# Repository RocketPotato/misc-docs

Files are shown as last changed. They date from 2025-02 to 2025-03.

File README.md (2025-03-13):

Unofficial Temporary location for RRLS Rudder Pedals BOM

This is a draft and not the official BOM. Use at your own risk. You will need to compare this with the CAD file avaiable on patreon to make sure you're getting the right parts. (Available here: https://patreon.com/RightRudderLeftStick)
BOM currently missing several parts. Mostly M5 and M8 nuts. Working onupdating and will upload soon. (I will delete this line when I do so)

Currently working on a quick-and-dirty joystick code to get this working with a Teesny 3.2 and adafruit MLX90393 (Teensy is about $35USD and MXL90393 is about $5 each) 
No rhyme or reason for choosing these boards. I had them on-hand. They are certianly more expensive than the bluepill solution used on the RRLS Very-Big-Stick and not compatible with freejoy or MMjoy so I cannot recommend them unless you already have them on hand.
Should work on a teensy 4 as well.
Currently have output from the board with good precision, repeatability, and sensitivity. However it's output as X/Y/Z componenet of the field vector so I'll need to turn that into an angle with some trig and then scale the output. 

This will be removed/hidden when the official BOM is available on patreon or publicly.

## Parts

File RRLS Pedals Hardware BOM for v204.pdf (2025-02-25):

RRLS Rudder Pedals | Version 204 BOM | Total: | | $ | -
(Distributed with cost section left blank due to significant variation in cost and availability of parts based on region)
Common Name | Name in drawing | Units | Unit Cost | Line Item Cost | Notes
Printed Parts | Section Total: $ | -
TBD | Look in drawing tree for details. Check in bodies subfolder to get all parts | Not listed. Guessing about 1.5 to 2kg, but still printing. (will vary significantly based on print settings)
Electronics | Section Total: $ | -
TBD | | | | | | Still in development. No hardware for mounting listed in this version of BOM
Bolts | Section Total: $ | -
M4 20mm SHCS | 91290A168_NO THREADS_Alloy Steel Socket Head Screw | 2 $ | - | $ | -
M5 8mm SHCS | 91290A222_NO THREADS_Alloy Steel Socket Head Screw | 5 $ | - | $ | -
M5 16mm SHCS | 91290A232_NO THREADS_Alloy Steel Socket Heads Screw | 21 $ | - | $ | -
M8 100mm SHCS | 91290A468_Alloy Steel Socket Head Screw | 2 $ | - | $ | - | Drawing shows shoulder bolts but nut placement requires all-thread
M5 20mm SHCS | 91290A242_NO THREADS_Alloy Steel Socket Head Screw | 19 $ | - | $ | -
M5 50mm SHCS | 91290A262_NO THREADS_Alloy Steel Socket Head Screw | 10 $ | - | $ | -
M8 60mm SHCS | 96144A235_Fine-Thread Alloy Steel Socket Head Screw | 4 $ | - | $ | -
M8 35mm SHCS | 96144A223_Fine-Thread Alloy Steel Socket Head Screw | 6 $ | - | $ | -
M6 25mm SHCS | 96144A125_Fine-Thread Alloy Steel Socket Head Screw | 4 $ | - | $ | -
Bearings | Section Total: $ | -
608 Bearing | 5972K501_Ball Bearing | 16 $ | - | $ | - | Does not include 4 608 bearings in toe brake add-on
6003 Bearing | 5972K325_Ball Bearing | 2 $ | - | $ | -
Nuts | Section Total: $ | -
M8 Nylock Nut | 94645A111_High-Strength Steel Nylon-Insert Locknut | 4 $ | - | $ | -
M5 Nylock Nut | 94645A102_NO THREADS_High-Strength Steel Nylon-Insert Locknut | 10 $ | - | $ | -
M8 Lock Washer | 92148A200_18-8 Stainless Steel Split Lock Washer | 2 $ | - | $ | -
M5 T-nut | Not in drawing | 21 $ | - | $ | - | Must be for 2020. Can be hard to find in US but there are a few ebay and amazon sellers
Toe Break Add-on (Optional) | Section Total: $ | - | See comments. BOM differs between fighter and airliner version
608 Bearing | 5972K501_Ball Bearing | 4 $ | - | $ | - | Both versions
M8 35mm SHCS | 96144A223_Fine-Thread Alloy Steel Socket Head Screw | 4 $ | - | $ | - | Both versions
M5 20mm SHCS | 91290A242_NO THREADS_Alloy Steel Socket Head Screw | 16 $ | - | $ | - | Both versions
M3 20mm SHCS | 91290A123_NO THREADS_Alloy Steel Socket Head Screw | 2 $ | - | $ | - | Both versions
M8 Washer | 98269A440_Black-Oxide 18-8 Stainless Steel Washer | 2 $ | - | $ | - | Both versions
M8 35mm SHCS | 96144A223_Fine-Thread Alloy Steel Socket Head Screw | 10 $ | - | $ | - | Combat Pedal Version Only
M5 20mm Flat Head Phillips 92010A328_NO THREADS_Passivated 18-8 stainless Steel Phillips Flat Head Screw 6 $ | - | $ | - | Airline Pedal Version Only
100mm RC Shock | 100mm-RCShock | 2 $ | - | $ | - | Both versions
Piston Damper add-on (optional) | Section Total: $ | -
M5 16mm SHCS | 91290A232_NO THREADS_Alloy Steel Socket Heads Screw | 1 $ | - | $ | -
M5 8mm SHCS | 91290A222_NO THREADS_Alloy Steel Socket Head Screw | 4 $ | - | $ | -
M8 Nylock Nut | 94645A111_High-Strength Steel Nylon-Insert Locknut | 1 $ | - | $ | -
M8 60mm SHCS | 96144A235_Fine-Thread Alloy Steel Socket Head Screw | 1 $ | - | $ | -
M5 T-nut | Not in drawing | 4 $ | - | $ | - | Counted anywhere bolt terminated in extrusion
Piston Damper | OH3A3-19L - ASSY, LEFT PITCH DAMPER | 1 $ | - | $ | - | Exact model unknown. Appears to come in more or less standard sizes
2020 Extrusion lengths | Section Total: $ | - | 1.6 meters needed. Usually sold in increments of 0.5 or 1m in the US
400mm | | 3 $ | - | $ | -
200mm | | 2 $ | - | $ | -
Misc | Section Total: $ | -
FRT-C2-301-G1 Rotary Damper | 2 $ | - | $ | - | optional. Currently only available with very long lead times in US
M4 8mm SHCS | 91290A113_Alloy Steel Socket Head Screw | 4 $ | - | $ | -
Extension Spring | 3630N293_Extenion Spring with Loop Ends | 1 $ | - | $ | - | Used for cam tension. Adjust as desired

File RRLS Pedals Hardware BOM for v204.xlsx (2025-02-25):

RRLS Rudder Pedals | Version 204 BOM |  |  |  | Total: | $37.71
 | pricing sourced from Fastenal in US as many bolts can be purchased individually. Cheaper sources can be found especially if buying in bulk
Common Name | Name in drawing | Units | Sold As | Order Qty | Unit Cost | Line Item Cost | Link | Notes
Printed Parts |  |  |  |  | Section Total: | $0.00
TBD | Look in drawing tree for details. Check in bodies subfolder to get all parts |  |  |  |  |  |  | Not listed. Guessing about 1.5 to 2kg, but still printing. (will vary significantly based on print settings)
Electronics |  |  |  |  | Section Total: | $0.00
TBD |  |  |  |  |  |  |  | Still in development. No hardware for mounting listed in this version of BOM
Bolts |  |  |  |  | Section Total: | $16.22
M4 20mm SHCS | 91290A168_NO THREADS_Alloy Steel Socket Head Screw | 2 | ea | 2 | $0.13 | $0.26 | https://www.fastenal.com/product/details/ZS2530020ZP0000#
M5 8mm SHCS | 91290A222_NO THREADS_Alloy Steel Socket Head Screw | 5 | ea | 5 | $0.09 | $0.43 | https://www.fastenal.com/product/details/11103206#
M5 16mm SHCS | 91290A232_NO THREADS_Alloy Steel Socket Heads Screw | 21 | ea | 21 | $0.10 | $2.17 | https://www.fastenal.com/product/details/ZS2540016ZP0000#
M8 100mm SHCS | 91290A468_Alloy Steel Socket Head Screw | 2 | ea | 2 | $0.55 | $1.10 | https://www.fastenal.com/product/details/0121814# | Drawing shows shoulder bolts but nut placement requires all-thread. Swapped to hex head
M5 20mm SHCS | 91290A242_NO THREADS_Alloy Steel Socket Head Screw | 19 | ea | 19 | $0.11 | $2.16 | https://www.fastenal.com/product/details/11103212#
M5 50mm SHCS | 91290A262_NO THREADS_Alloy Steel Socket Head Screw | 10 | ea | 10 | $0.48 | $4.82 | https://www.fastenal.com/product/details/MS2540050A20000#
M8 60mm SHCS | 96144A235_Fine-Thread Alloy Steel Socket Head Screw | 4 |  | 4 | $0.49 | $1.95 | https://www.fastenal.com/product/details/11113827# | Selected hex head bolt
M8 35mm SHCS | 96144A223_Fine-Thread Alloy Steel Socket Head Screw | 6 |  | 6 | $0.43 | $2.60 | https://www.fastenal.com/product/details/ZS2580035ZP0000#
M6 25mm SHCS | 96144A125_Fine-Thread Alloy Steel Socket Head Screw | 4 |  | 4 | $0.18 | $0.74 | https://www.fastenal.com/product/details/ZS2550025ZP0000#
Bearings |  |  |  |  | Section Total: | $0.00
608 Bearing | 5972K501_Ball Bearing | 16 |  | 16 | $0.00 | $0.00 | Amazon (for return policy) | Does not include 4 608 bearings in toe brake add-on
6003 Bearing | 5972K325_Ball Bearing | 2 |  | 2 | $0.00 | $0.00 | Amazon (for return policy)
Nuts |  |  |  |  | Section Total: | $4.11
M8 Nylock Nut | 94645A111_High-Strength Steel Nylon-Insert Locknut | 4 |  | 4 | $0.59 | $2.36 | https://www.fastenal.com/product/details/1L2580000A40000#
M5 Nylock Nut | 94645A102_NO THREADS_High-Strength Steel Nylon-Insert Locknut | 10 |  | 10 | $0.16 | $1.63 | https://www.fastenal.com/product/details/1L2540000A40000#
M8 Lock Washer | 92148A200_18-8 Stainless Steel Split Lock Washer | 2 |  | 2 | $0.06 | $0.11 | https://www.fastenal.com/product/details/40252#
M5 T-nut | Not in drawing | 21 |  | 21 | $0.00 | $0.00 | Amazon (for return policy) | Must be for 2020. Can be hard to find in US but there are a few ebay and amazon sellers
Toe Break Add-on (Optional) |  |  |  |  | Section Total: | $12.79 |  | See comments. BOM differs between fighter and airliner version
608 Bearing | 5972K501_Ball Bearing | 4 |  | 4 | $0.00 | $0.00 | Amazon (for return policy) | Both versions
M8 35mm SHCS | 96144A223_Fine-Thread Alloy Steel Socket Head Screw | 4 |  | 4 | $0.43 | $1.73 | https://www.fastenal.com/product/details/ZS2580035ZP0000# | Both versions
M5 20mm SHCS | 91290A242_NO THREADS_Alloy Steel Socket Head Screw | 16 |  | 16 | $0.11 | $1.82 | https://www.fastenal.com/product/details/11103212# | Both versions
M3 20mm SHCS | 91290A123_NO THREADS_Alloy Steel Socket Head Screw | 2 |  | 2 | $0.00 | $0.00 |  | Both versions
M8 Washer | 98269A440_Black-Oxide 18-8 Stainless Steel Washer | 2 |  | 2 | $0.11 | $0.21 | https://www.fastenal.com/product/details/MW6380000A40000# | Both versions
M8 35mm SHCS | 96144A223_Fine-Thread Alloy Steel Socket Head Screw | 10 |  | 10 | $0.43 | $4.34 | https://www.fastenal.com/product/details/ZS2580035ZP0000# | Combat Pedal Version Only
M5 20mm Flat Head Phillips | 92010A328_NO THREADS_Passivated 18-8 stainless Steel Phillips Flat Head Screw | 6 |  | 6 | $0.00 | $0.00 |  | Airline Pedal Version Only. No source. Can't find reasonably priced source (didn't try very hard)
100mm RC Shock | 100mm-RCShock | 2 |  | 2 | $0.00 | $0.00 |  | Both versions
Piston Damper add-on (optional) |  |  |  |  | Section Total: | $4.59
M5 16mm SHCS | 91290A232_NO THREADS_Alloy Steel Socket Heads Screw | 1 |  | 1 | $0.10 | $0.10 | https://www.fastenal.com/product/details/ZS2540016ZP0000#
M5 8mm SHCS | 91290A222_NO THREADS_Alloy Steel Socket Head Screw | 4 |  | 4 | $0.85 | $3.40 | https://www.fastenal.com/product/details/11103206#
M8 Nylock Nut | 94645A111_High-Strength Steel Nylon-Insert Locknut | 1 |  | 1 | $0.59 | $0.59 | https://www.fastenal.com/product/details/0121814#
M8 60mm SHCS | 96144A235_Fine-Thread Alloy Steel Socket Head Screw | 1 |  | 1 | $0.49 | $0.49 | https://www.fastenal.com/product/details/11113827#
M5 T-nut | Not in drawing | 4 |  | 4 | $0.00 | $0.00 | Amazon (for return policy) | Counted anywhere bolt terminated in extrusion
Piston Damper | OH3A3-19L - ASSY, LEFT PITCH DAMPER | 1 |  | 1 | $0.00 | $0.00 | Amazon (for return policy) | Exact model unknown. Appears to come in more or less standard sizes
2020 Extrusion lengths |  |  |  |  | Section Total: | $0.00 |  | 1.6 meters needed. Usually sold in increments of 0.5 or 1m in the US
400mm |  | 3 |  | 3 | $0.00 | $0.00
200mm |  | 2 |  | 2 | $0.00 | $0.00
Misc |  |  |  |  | Section Total: | $0.00
FRT-C2-301-G1 Rotary Damper |  | 2 |  | 2 | $0.00 | $0.00 |  | optional. Currently only available with very long lead times in US
M4 8mm SHCS | 91290A113_Alloy Steel Socket Head Screw | 4 |  | 4 | $0.00 | $0.00
Extension Spring | 3630N293_Extenion Spring with Loop Ends | 1 |  | 1 | $0.00 | $0.00 |  | Used for cam tension. Adjust as desired

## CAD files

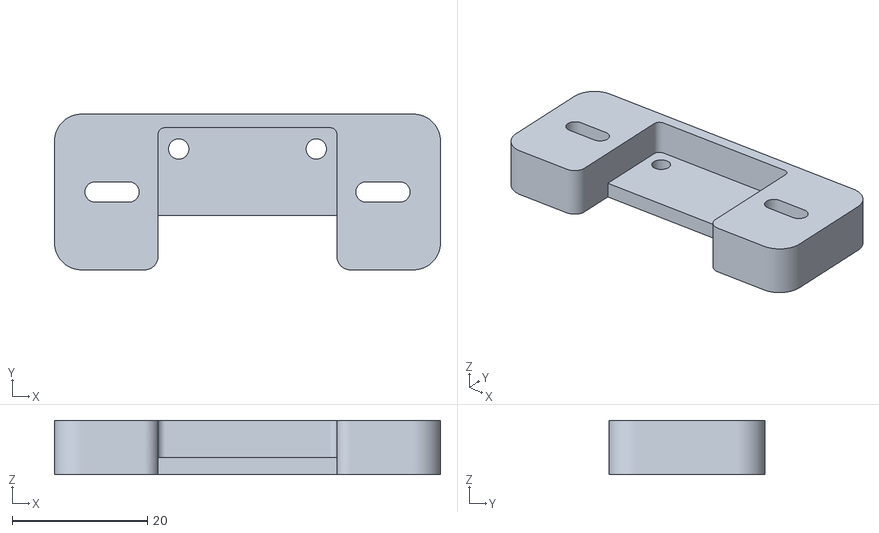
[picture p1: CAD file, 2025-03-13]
Adafruit MXL30393 Breakout Board Mount.stl
57.0 x 23.0 x 8.00

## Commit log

2025-02-25 Add files via upload
    Added BOM file for os-vbs rudder pedals v204 CAD
    [RRLS Pedals Hardware BOM for v204.xlsx]
2025-02-25 Update RRLS Pedals Hardware BOM for v204.xlsx
    Included pricing from one possible source. (Fastenal)
    Pricing is not complete.
    [RRLS Pedals Hardware BOM for v204.xlsx]
2025-03-13 Create Adafruit MXL30393 Breakout Board Mount.stl
    [Adafruit MXL30393 Breakout Board Mount.stl]
